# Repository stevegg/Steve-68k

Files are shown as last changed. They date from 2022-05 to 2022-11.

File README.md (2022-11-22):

# Steve's 68k

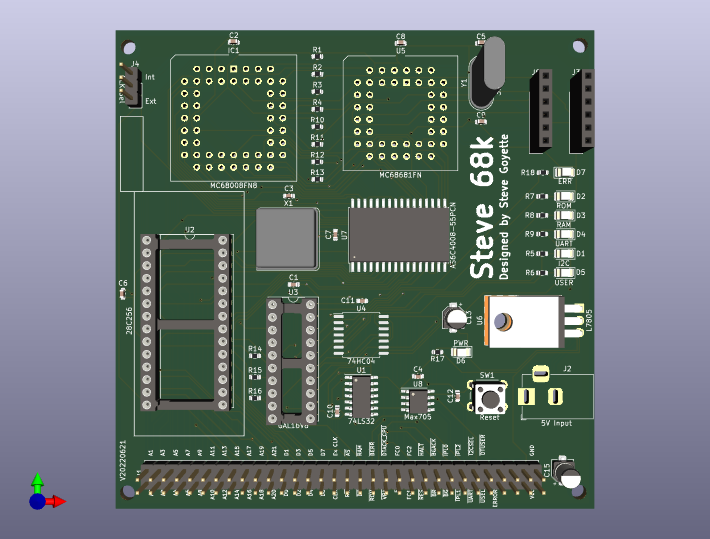
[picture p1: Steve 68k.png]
Steve 68k


This is my extremely simple 68000 single board computer.  It has 512k of ROM and 512k of RAM.

## What's the Point?

I'm building this to learn the fundamentals of microprocessors and their use in computer systems.  Modern day computers are complex and require specific supporting chip sets.  These retro processors were simple and much easier to understand but in the end the principles are the same.

This design **HEAVILLY** borrows from [Neil Klingensmith](https://neilklingensmith.com/teaching/68khomebrew/) whose explanations really helped me grasp some of the fundamentals.

V20220621 was sent for fab on the evening of June 21, 2022.  This version's changes:
- 5v input via Barrel Plug and uses a 7805 to regulate the voltage
- Changes from 1.8432Mhz Clock Oscillator to a 3.6864Mhz for the UART CLK
- Added pull-up resistors for the DTACK input lines to the GAL
- Added an ERROR indicator LED and ERROR output line to the BUS
- Changed Serial connectors to standard FTDDI connector layout
- Added RTS and CTS lines to Serial connector pulled from the IP and OP ports on the 68681
- Fixed D0 label on BUS (was A0)
- Added A17 and A18 to the GAL to allow for more fine grained address decoding
- Other minor fixes

Still having a problem with serial input....challenges are what make the victory sweeter I suppose.

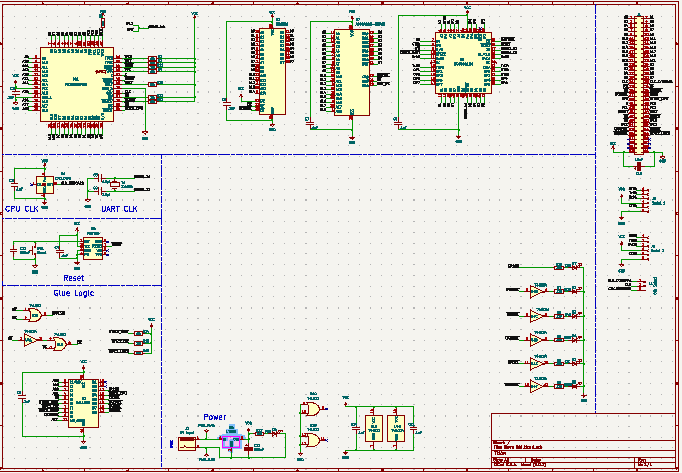
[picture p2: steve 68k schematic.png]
Schematic


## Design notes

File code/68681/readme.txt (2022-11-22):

 Enhanced BASIC is a BASIC interpreter for the 68k family microprocessors. It
 is constructed to be quick and powerful and easily ported between 68k systems.
 It requires few resources to run and includes instructions to facilitate easy
 low level handling of hardware devices. It also retains most of the powerful
 high level instructions from similar BASICs.

 EhBASIC is free but not copyright free. For non commercial use there is only one
 restriction, any derivative work should include, in any binary image distributed,
 the string "Derived from EhBASIC" and in any distribution that includes human
 readable files a file that includes the above string in a human readable form
 e.g. not as a comment in an HTML file.

 For commercial use please contact me,  Lee Davison, at leeedavison@lycos.co.uk
 for conditions.

 For more information on EhBASIC68, other versions of EhBASIC and other projects
 please visit my site at ..

	 http://members.lycos.co.uk/leeedavison/index.html

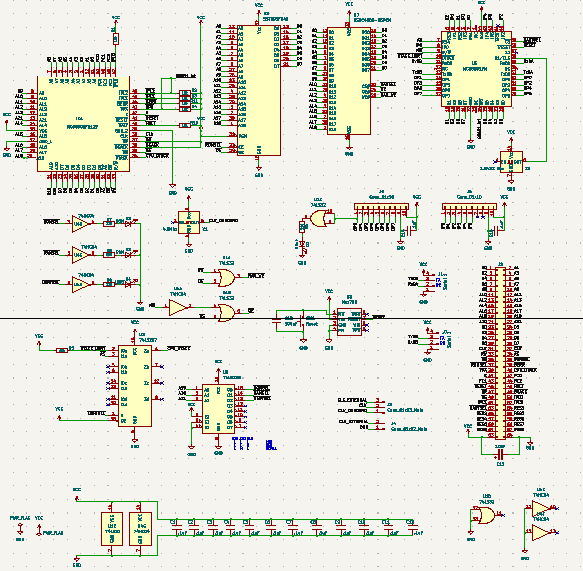
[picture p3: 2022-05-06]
hardware/steve 68k schematic.png

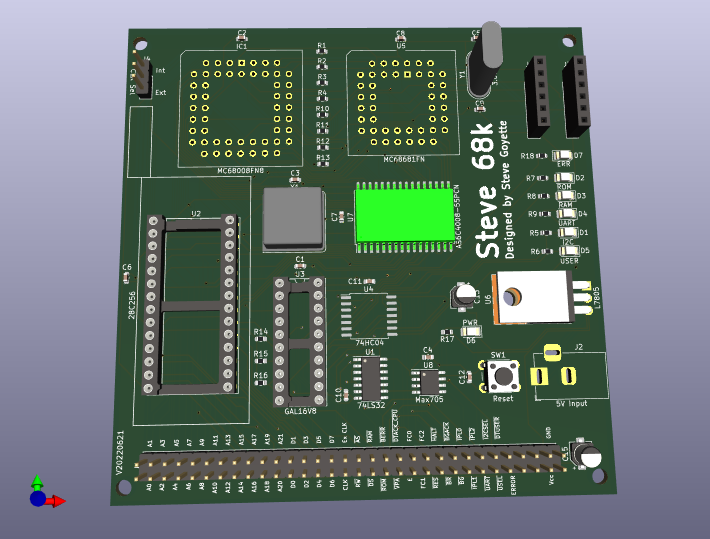
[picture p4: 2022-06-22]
hardware/Steve 68k.png

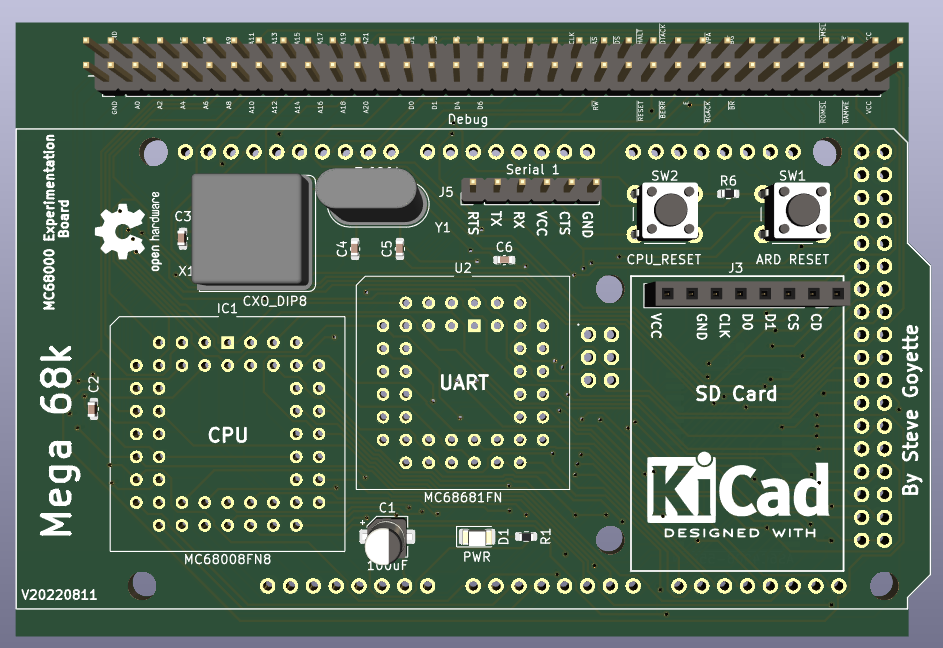
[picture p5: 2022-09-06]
V20220811.png

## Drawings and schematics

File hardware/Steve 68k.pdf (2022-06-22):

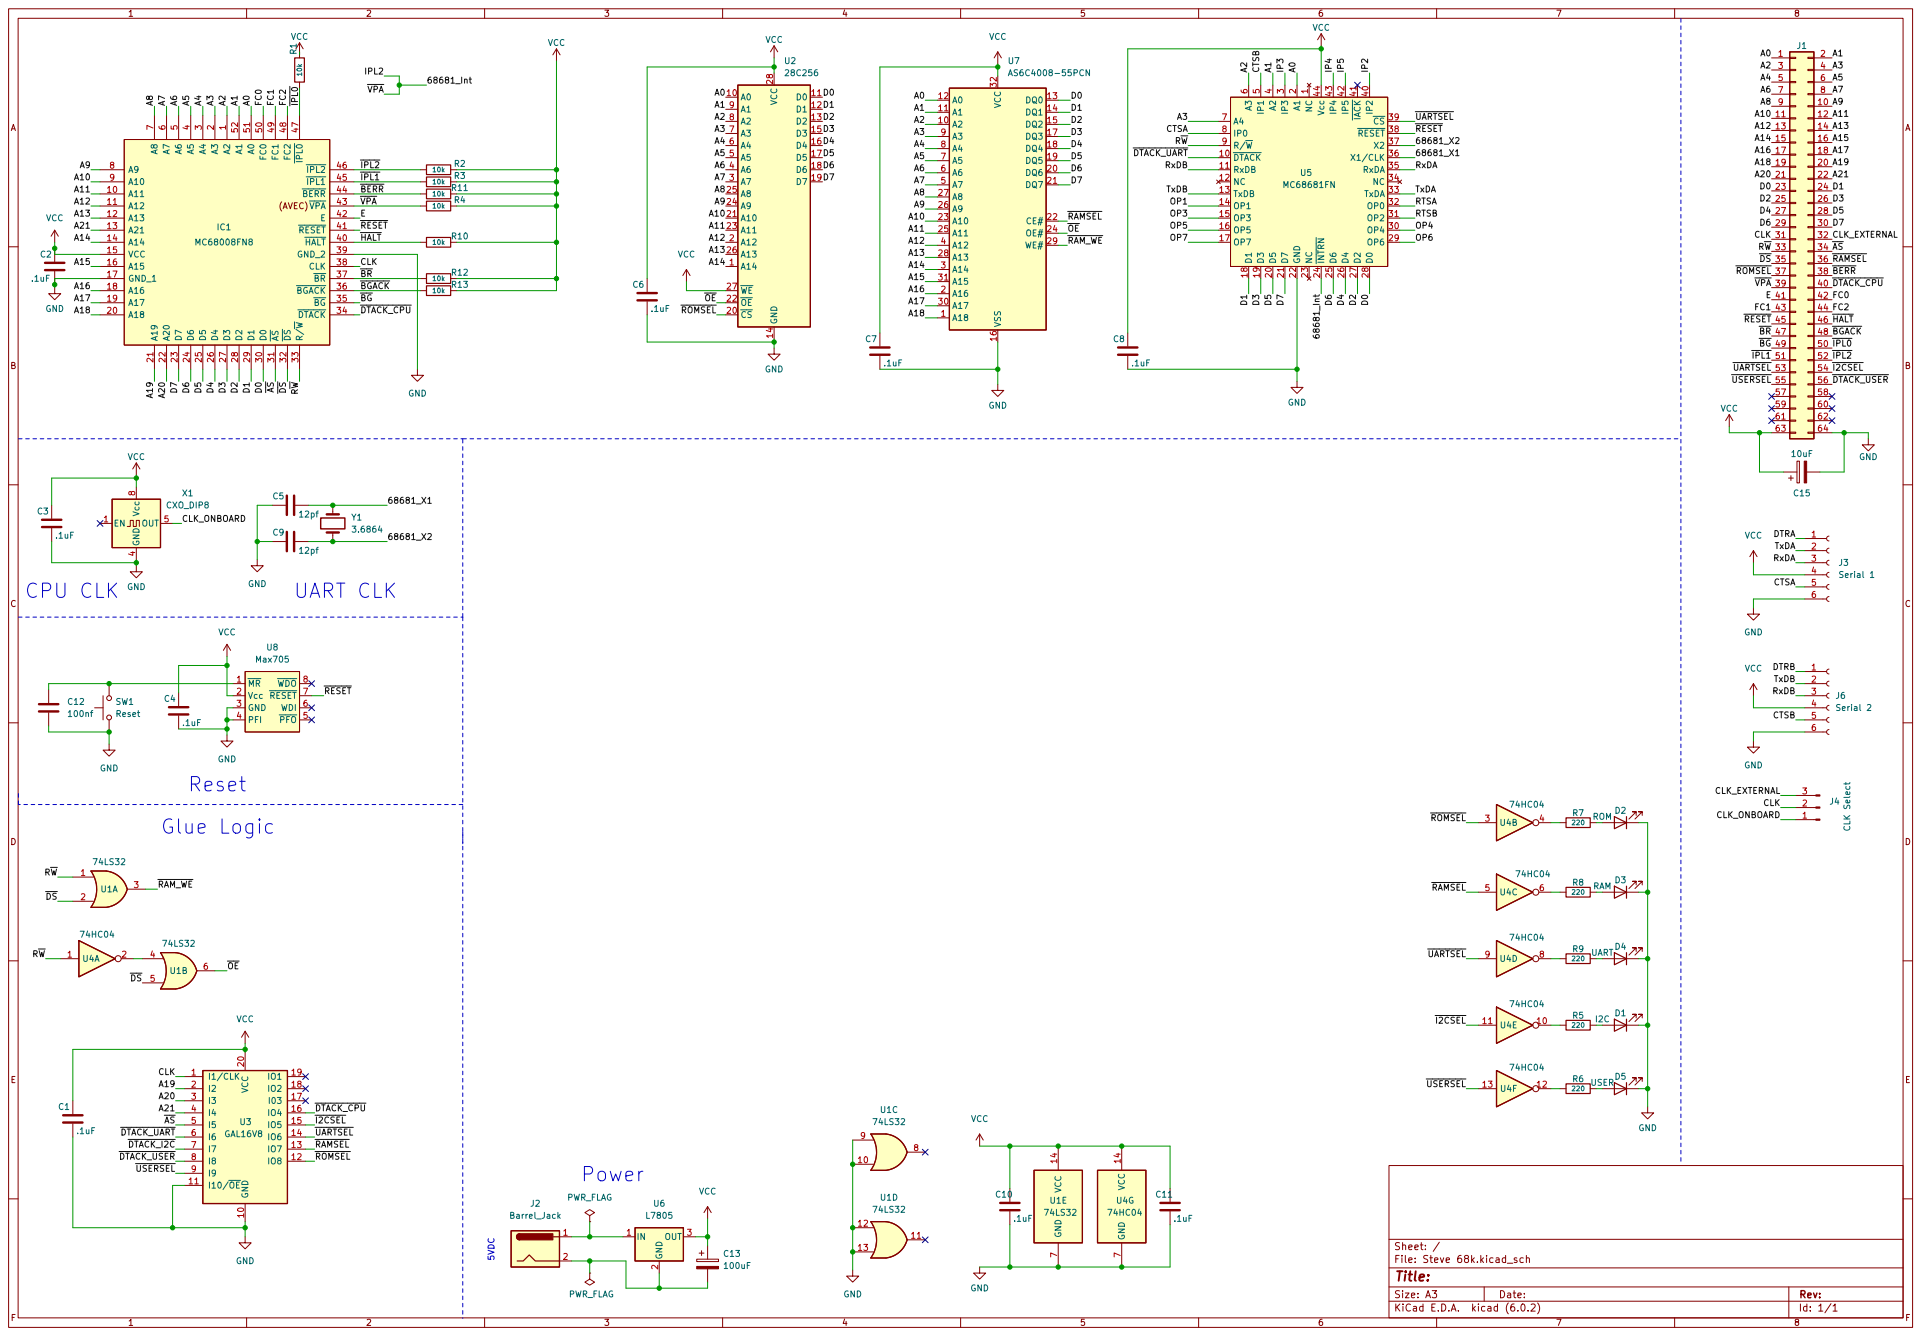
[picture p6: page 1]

1 ~{DTACK} 10 RxDB 11 NC 12 TxDB 13 OP1 14 OP3 15 OP5 16 OP7 17 D1 18 D3 19 A1

3 OP4 30 OP2 31 OP0 32 TxDA 33 NC 34 RxDA 35 X1/CLK 36 X2 37 ~{RESET}38 ~{CS}39 A2

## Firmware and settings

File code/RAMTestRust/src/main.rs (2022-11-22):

#![no_std]

// use core::ptr;
use core::panic::PanicInfo;

// memory map
// const ROMBASE:  *mut u32 = 0x000000 as *mut u32;         // Base address for ROM space
const RAMBASE:  *mut u32 = 0xE00000 as *mut u32;         // Base address for RAM
// const RAMLIMIT: *mut u32 = 0xE0FFFF as *mut u32;         // Limit of onboard RAM
const ERRIND:   *mut u32 = 0xF00000 as *mut u32;
const TESTLIMIT:*mut u32 = 0xE00F00 as *mut u32;

#[panic_handler]
fn panic(_info: &PanicInfo) -> ! {
    loop {}
}

fn main() {}

// fn main() {

//     loop {
//         let mut ram_ptr: *mut u32 = RAMBASE;
//         loop {
//             unsafe {
//                 ptr::write(ram_ptr, 0x00);
//                 let n = ptr::read(ram_ptr);
//                 ram_ptr = ram_ptr.add(1);
//                 if n != 0x00 {
//                     ptr::write(ERRIND, n);
//                 }
//             }

//             if ram_ptr == TESTLIMIT {
//                 break;
//             }

//         }
//     }
// }

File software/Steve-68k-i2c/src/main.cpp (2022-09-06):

#include <Arduino.h>
#include <Adafruit_GFX.h>
#include <Adafruit_LEDBackpack.h>

/**
 * Fuse settings for ATMega 1284 for 16mhz external oscillator
 * Low Byte: 0xFF (blank all)
 * High Byte: 0xDE (Check SPIEN and BOOTRST)
 * Extended: 0xFD (Check BODLEVEL1)
 * 
 * Port Manipulation
 *    DDR 1 = OUTPUT, 0 = INPUT
 *    Use PIN to read
 *    Use PORT to write
 * 
 */

Adafruit_7segment matrix = Adafruit_7segment();

volatile boolean processBus = false;

#define I2C_SEL_PIN   2
#define I2C_DTACK     PINC6
#define RW_PIN        PIND2

#define DATA_PORT     PORTA
#define ADDRESS_LOW   PORTC

// Called whenever the I2C_SEL pin goes LOW
void processBusInterruptHandler() {

  processBus = true;

}

void setup() {

  Serial.begin(9600);

  // Setup Data Port initially as INPUT
  DDRA = 0x00;
  // Setup Address Low as INPUT
  DDRC &= ~((1<<PINC2) | (1<<PINC3) | (1<<PINC4) | (1<<PINC5));

  // I2C_DTACK is an OUTPUT
  DDRC |= (1<<I2C_DTACK);
  // Set it's state to HI
  PORTC |= (1<<I2C_DTACK);

  // I2C_SEL is an INPUT
  pinMode(I2C_SEL_PIN, INPUT);

  // Setup an interrupt on the I2C_SEL pin

  matrix.begin(0x70);
  // Show Rdy on Display
  matrix.print("Rdy");
  matrix.writeDisplay();

  attachInterrupt(digitalPinToInterrupt(I2C_SEL_PIN), processBusInterruptHandler, FALLING);

  Serial.println("Initialization complete.");
}

void loop() {

  if ( processBus ) {
    // Check RW
    bool reading = (PIND & (1<<RW_PIN)) == 1;
    char buffer[128];
    // Get the address
    byte address = ADDRESS_LOW & ((1<<PINC2)|(1<<PINC3)|(1<<PINC4)|(1<<PINC5));
    byte data = PINA;

    sprintf(buffer, "SEL: %c %02X : %02X", (reading)?'R':'W', address, data);
    Serial.println(buffer);

    if ( !reading ) {
      if ( address == 0x00 ) {
        // Write data to the 7 segment LED
        matrix.print(data, HEX);
        matrix.writeDisplay();
      } else if ( address == 0x01) {
        // Write data to the Serial port
        Serial.write(data);
      }
    }

    delay(1000);

    processBus = false;    
    // Now assert I2C_DTACK
    PORTC &= ~(1<<I2C_DTACK);
    delayMicroseconds(10);
    PORTC |= (1<<I2C_DTACK);


  }
}

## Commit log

2022-05-06 Initial Commit after fab
    [Steve 68k-B_Cu.gbr, Steve 68k-B_Mask.gbr, Steve 68k-B_Paste.gbr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]
2022-05-06 Moved some things around
    [Steve 68k-B_Cu.gbr, Steve 68k-B_Mask.gbr, Steve 68k-B_Paste.gbr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]
2022-05-06 Final re-org of files (for now)
    [Steve 68k-B_Cu.gbr, Steve 68k-B_Mask.gbr, Steve 68k-B_Paste.gbr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]
2022-05-06 Added schematic to readme
    [Steve 68k.kicad_sch]
2022-05-08 Fixed Dtack select
    [Steve 68k.kicad_sch]
2022-05-19 Serial Test and some changes to the PCB
    [Steve 68k.dsn, Steve 68k.kicad_pcb, Steve 68k.kicad_sch]
2022-06-01 Working on PLD for Glue Logic
    [Steve 68k.dsn, Steve 68k.kicad_pcb, Steve 68k.kicad_sch]
2022-06-01 New version of PCB using a GAL
    [Steve 68k-B_Cu.gbr, Steve 68k-B_Mask.gbr, Steve 68k-B_Paste.gbr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]
2022-06-02 More GAL and glue logic stuff
    [Steve 68k.kicad_sch]
2022-06-13 Rev V20220601
    [Steve 68k.kicad_pcb, Steve 68k.kicad_sch]
2022-06-13 Updated board view to the latest
2022-06-22 Latest version sent for fab
    [Steve 68k-B_Cu.gbr, Steve 68k-B_Mask.gbr, Steve 68k-B_Paste.gbr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]
2022-06-22 Updated board image
2022-06-22 Redid board image and moved it
2022-06-22 Board Schematic image and PDF
    [Steve 68k.kicad_pcb]
2022-09-06 V20220905 sent for fab
    [Steve 68k-B_Cu.gbr, Steve 68k-B_Mask.gbr, Steve 68k-B_Paste.gbr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]
2022-11-10 More progress
    [CPU Board.kicad_sch]
2022-11-12 UART outputting at 433baud...but working
2022-11-12 UART outputting at 433baud...but working (missing files)
    [UARTTest.asm]
2022-11-14 Added a status output board
    [Protoboard-B_Cu.gbl, Protoboard-B_Mask.gbs, Protoboard-B_Paste.gbp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]
